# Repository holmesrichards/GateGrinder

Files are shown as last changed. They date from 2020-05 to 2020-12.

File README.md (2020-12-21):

# GateGrinder
Kosmo format synth module, 10 cm wide, to generate clocks and act on triggers and gates (called “signals” generally herein).

Signals come from three sources. There is a jack for an external CV input (±12V). There is a pushbutton for manually created gates. Finally, there is an internal clock to produce a stream of square gates. The clock can be switched On or Off and to Slow or Fast rate ranges, and its Rate can be set, on the front panel. (Slow is around 0.14 Hz to 15 Hz, fast is 3.2 Hz to 320 Hz using the specified components.)

If the Resize On/Off switch is set to Off, the OR of these three signal sources is sent to the Out jack. Otherwise the rising edges are used to trigger a one-shot whose output width is controlled by the Resize Narrow/Wide switch and the Width knob, and the resulting signals are sent to Out. Output widths can vary from about a few milliseconds to about 5 seconds.

(And yes, the width can be set to longer than the time between two pulses. It then ignores any pulses that come along until the resized pulse ends.)

The signal at the Out jack also goes to an inverter whose output goes to the ~Out jack. LEDs indicate when Out and ~Out are on. The rising and falling edges of the Out signal are used to generate trigger pulses which go to the On and Off jacks respectively.

So one can invert gates, change the lengths of gates, convert gates to triggers, convert triggers to gates, make a gate clock, make a trigger clock.

Repository at https://github.com/holmesrichards/GateGrinder includes KiCad format schematic, PCB design, and panel design. Latest versions in the repository contain  modifications I have not tested though others have reported they work; see tagged releases for versions I have verified.

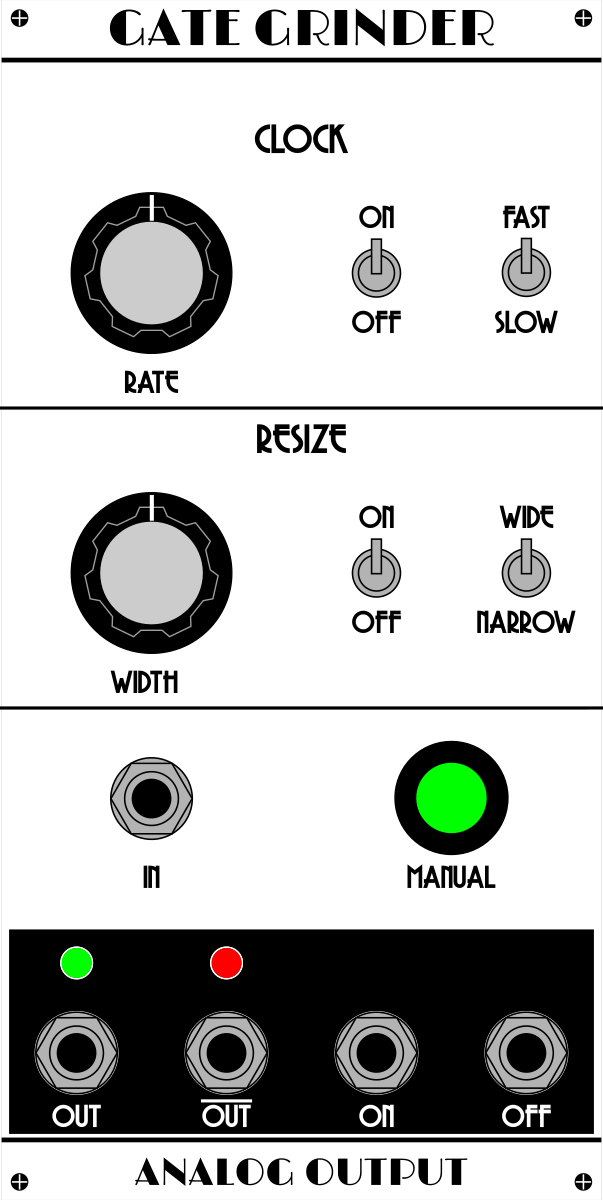
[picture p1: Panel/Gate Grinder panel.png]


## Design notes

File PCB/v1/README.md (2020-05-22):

# v1
This folder contains schematics, PCB, build notes, and BOM for the module as originally fabricated. PCB is too long and contains regular instead of wide transistor footprints. Outputs have fixed resistor voltage dividers instead of trimmer pots.

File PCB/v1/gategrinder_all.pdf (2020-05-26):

# GateGrinder

Kosmo format synth module, 10 cm wide, to generate clocks and act on triggers and gates (called “signals” generally herein).

Signals come from three sources. There is a jack for an external CV input (±12V). There is a pushbutton for manually created gates. Finally, there is an internal clock to produce a stream of square gates. The clock can be switched On or Off and to Slow or Fast rate ranges, and its Rate can be set, on the front panel. (Slow is around 0.14 Hz to 15 Hz, fast is 3.2 Hz to 320 Hz using the specified components.)

If the Resize On/Off switch is set to Off, the OR of these three signal sources is sent to the Out jack. Otherwise the rising edges are used to trigger a one-shot whose output width is controlled by the Resize Narrow/Wide switch and the Width knob, and the resulting signals are sent to Out. Output widths can vary from about a few milliseconds to about 5 seconds.

(And yes, the width can be set to longer than the time between two pulses. It then ignores any pulses that come along until the resized pulse ends.)

The signal at the Out jack also goes to an inverter whose output goes to the ~Out jack. LEDs indicate when Out and ~Out are on. The rising and falling edges of the Out signal are used to generate trigger pulses which go to the On and Off jacks respectively.

So one can invert gates, change the lengths of gates, convert gates to triggers, convert triggers to gates, make a gate clock, make a trigger clock.

Repository at https://github.com/holmesrichards/GateGrinder includes KiCad format schematic, PCB design, and panel design.

# Gate Grinder build notes

These build notes are for the first version of Gate Grinder. For the current version see https://github.com/holmesrichards/GateGrinder/blob/master/BUILD_NOTES.md (https://github.com/holmesrichards/GateGrinder/blob/master/BUILD_NOTES.md) . Differences pertain only to the main PCB.

This is a pretty standard Kosmo module. There are two PCBs, a large main one and a smaller panel PCB.

For some incomprehensible reason I made the main board about 15 mm too long to fit in a Kosmo case and then didn’t use the bottom 15 mm. Use a cutting wheel on a Dremel to cut 15 mm off the bottom of the main board (where the logo is).

Most components go on the rear of the main board. Jacks, LEDs, and push button go on the front of the main board along with a 1x14 pin header. Toggle switches and pots go on the front of the panel board and a 1x14 pin socket goes on the rear. Panel and main board are joined via the pin header/ socket and two 12 mm M3 spacers.

Toggle switches and pots need all nuts and washers removed before placing the panel. LEDs need either to have long enough legs to reach the main board or to have their legs extended with pieces of wire. The recommended push button fits the panel hole and, assuming a 1.6 mm panel, the solder lugs just barely extend to and through the main board. Note that since it is installed from the front of the panel, once it has been soldered the panel cannot be removed without cutting the push button loose.

With components as specified, the output levels are low, just under 4V. Replacing the 1.8k resistors in the output voltage dividers (R19, R21, R23, R25) with 1.2k will bring these up to 5V, or adjust however you like to suit your preferences.

BOM for the main board is here: https://github.com/holmesrichards/GateGrinder/blob/master/PCB/v1/gategrinder_v1_bom.md

BOM for the panel board is here: https://github.com/holmesrichards/GateGrinder/blob/master/PanelPCB/gategrinder_panelPCB_bom.md

# gategrinder BOM

Thu 14 May 2020 10:39:47 AM EDT

Generated from schematic by Eeschema 5.1.5-52549c5~84~ubuntu18.04.1

This is BOM for the main PCB only

These build notes are for the first version of Gate Grinder. For the current version see https://github.com/holmesrichards/GateGrinder/blob/master/gategrinder_bom.md (https://github.com/holmesrichards/GateGrinder/blob/master/gategrinder_bom.md) . Differences pertain only to the main PCB.

Component Count: 68
Value | Qty | Part | Description | Vendor
C1, C12 | 2 | 0.01uF | Unpolarized capacitor
C2, C14 | 2 | 2.2uF | Polarized capacitor
C3, C7, C8, C10, C11, C13 | 6 | 0.1uF | Unpolarized capacitor
C4, C17 | 2 | 47uF | Polarized capacitor
C5, C6 | 2 | 10uF | Polarized capacitor
C9, C15, C16 | 3 | 100pf | Unpolarized capacitor
D1, D2 | 2 | 1N5817 | 20V 1A Schottky Barrier Rectifier Diode, DO-41
D3, D4, D5, D6 | 4 | 1N4148 | 100V 0.15A standard switching diode, DO-35
D7, D8 | 2 | LED | Light emitting diode
J1 | 1 | EURO_PWR_2x5 Eurorack style power header
J3 | 1 | Conn_01x14 | Pin header, male 14 pins
J6, J7, J8, J9, J10 | 5 | AudioJack | ¼" Audio Jack
Q1, Q2, Q3, Q4, Q5 | 5 | BC547 | 0.1A Ic, 45V Vce, Small Signal NPN Transistor, TO-92
R1, R12, R20, R22, R24, R26 | 6 | 1k | Resistor
R2, R5, R6, R7, R9, R10, R13, R14, R17, R18 10 100k | Resistor
R3 | 1 | 1M | Resistor
R4, R11 | 2 | 10k | Resistor
R8 | 1 | 15k | Resistor
R15, R16 | 2 | RL | Resistor
R19, R21, R23, R25 | 4 | 1k8 | Resistor
SW3 | 1 | SW_Push | Push button switch, solder lugs, Tayda A-4326
U1 | 1 | NA556 | Dual Precision Timers, DIP-14/SOIC-14/SSOP-14
U2 | 1 | 4069 | Hex inverter
U3 | 1 | TL072 | Dual Low-Noise JFET-Input Operational Amplifiers, DIP-8/SOIC-8
U4 | 1 | 4071 | Quad Or 2 inputs
Also needed/recommended:

1 IC socket, 8 pin
3 IC sockets, 14 pin
1 Eurorack style power cable
2 knobs (I used MF-A03, Tayda A-1006) 4 M3x6mm screws
2 spacers, 12 mm, Tayda A-3317
4 Mounting screws

# gategrinder_panelPCB BOM

Mon 18 May 2020 11:31:23 PM EDT

Generated from schematic by Eeschema 5.1.5-52549c5~84~ubuntu18.04.1

This is BOM for the panel PCB only

Component Count: 7
Value Qty | Part | Description | Vendor
J1 | 1 | Conn_01x14 Pin socket, female 14 pins
RV1, RV2 2 | 100K | Potentiometer, 9 mm board mount, Tayda A-1848
SW1, SW3 2 | SW_SPST | Single Pole Single Throw (SPST) switch
SW2, SW4 2 | SW_SPDT | Switch, single pole double throw

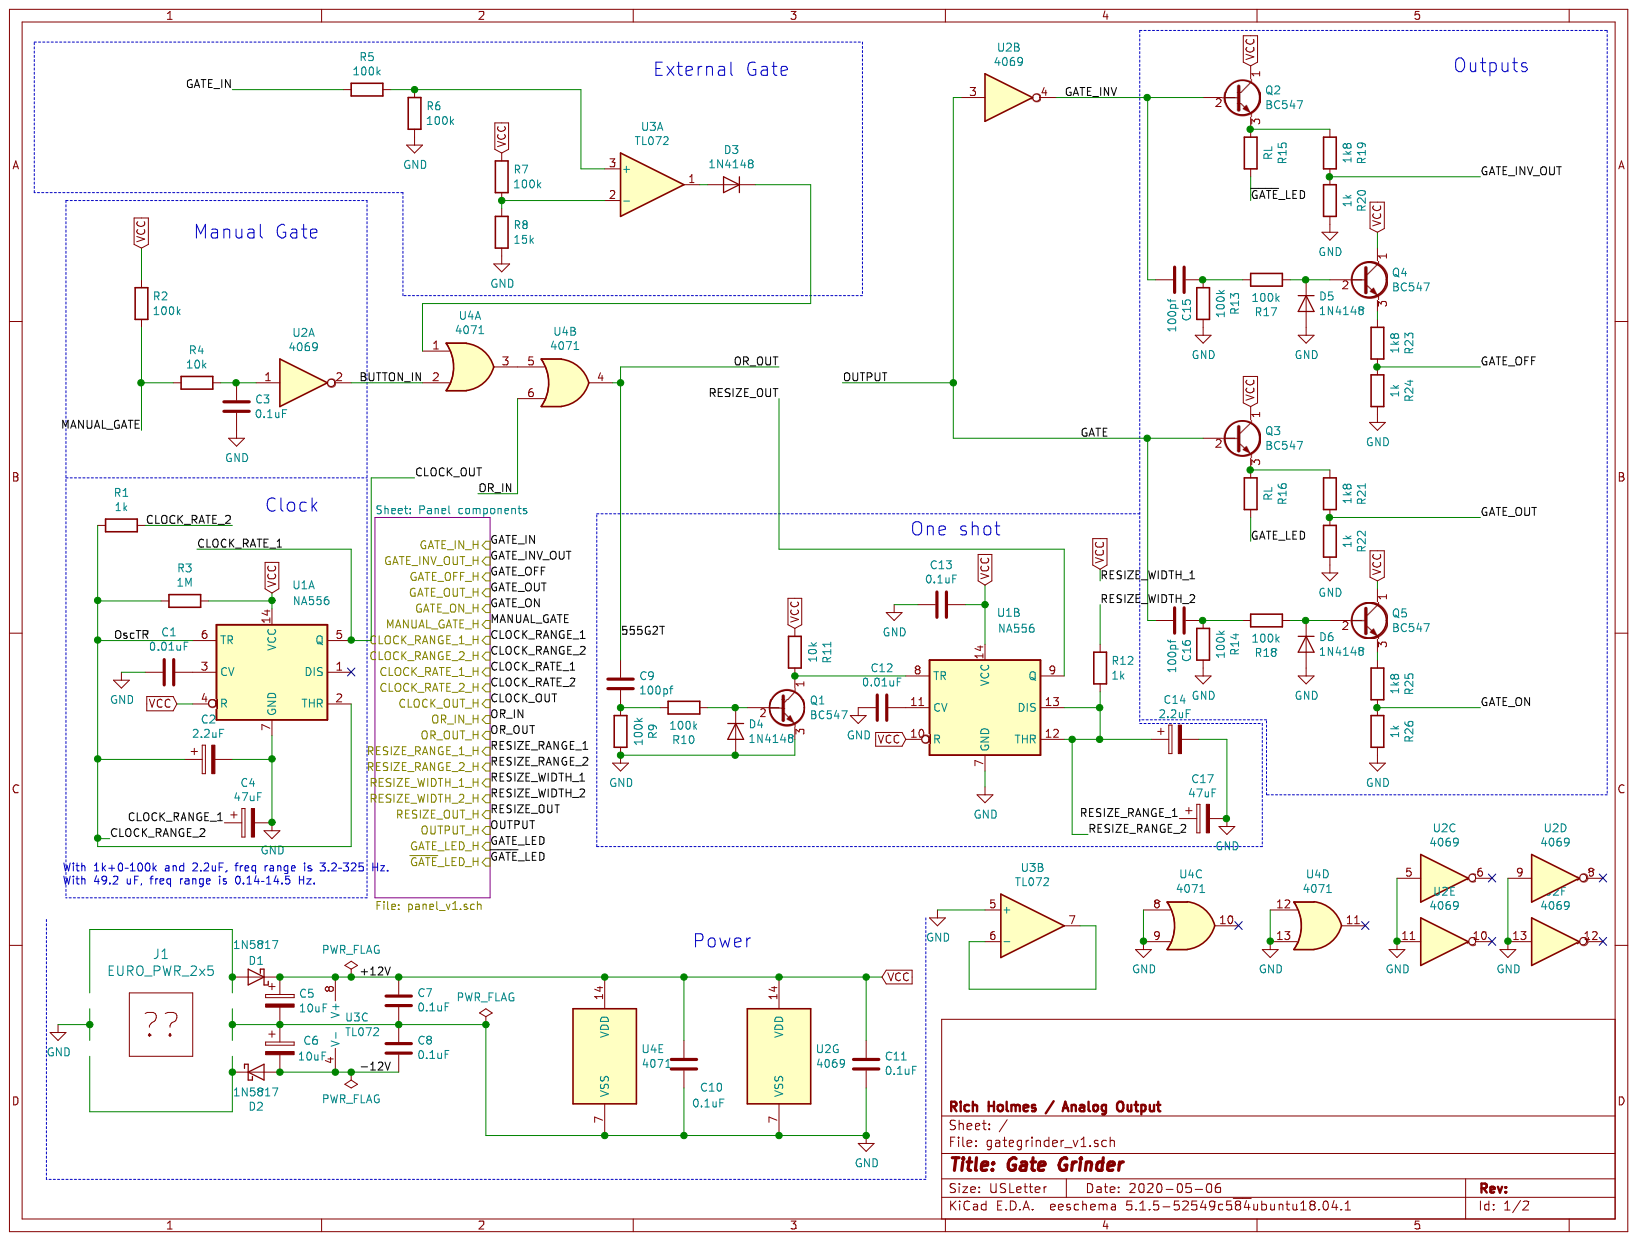
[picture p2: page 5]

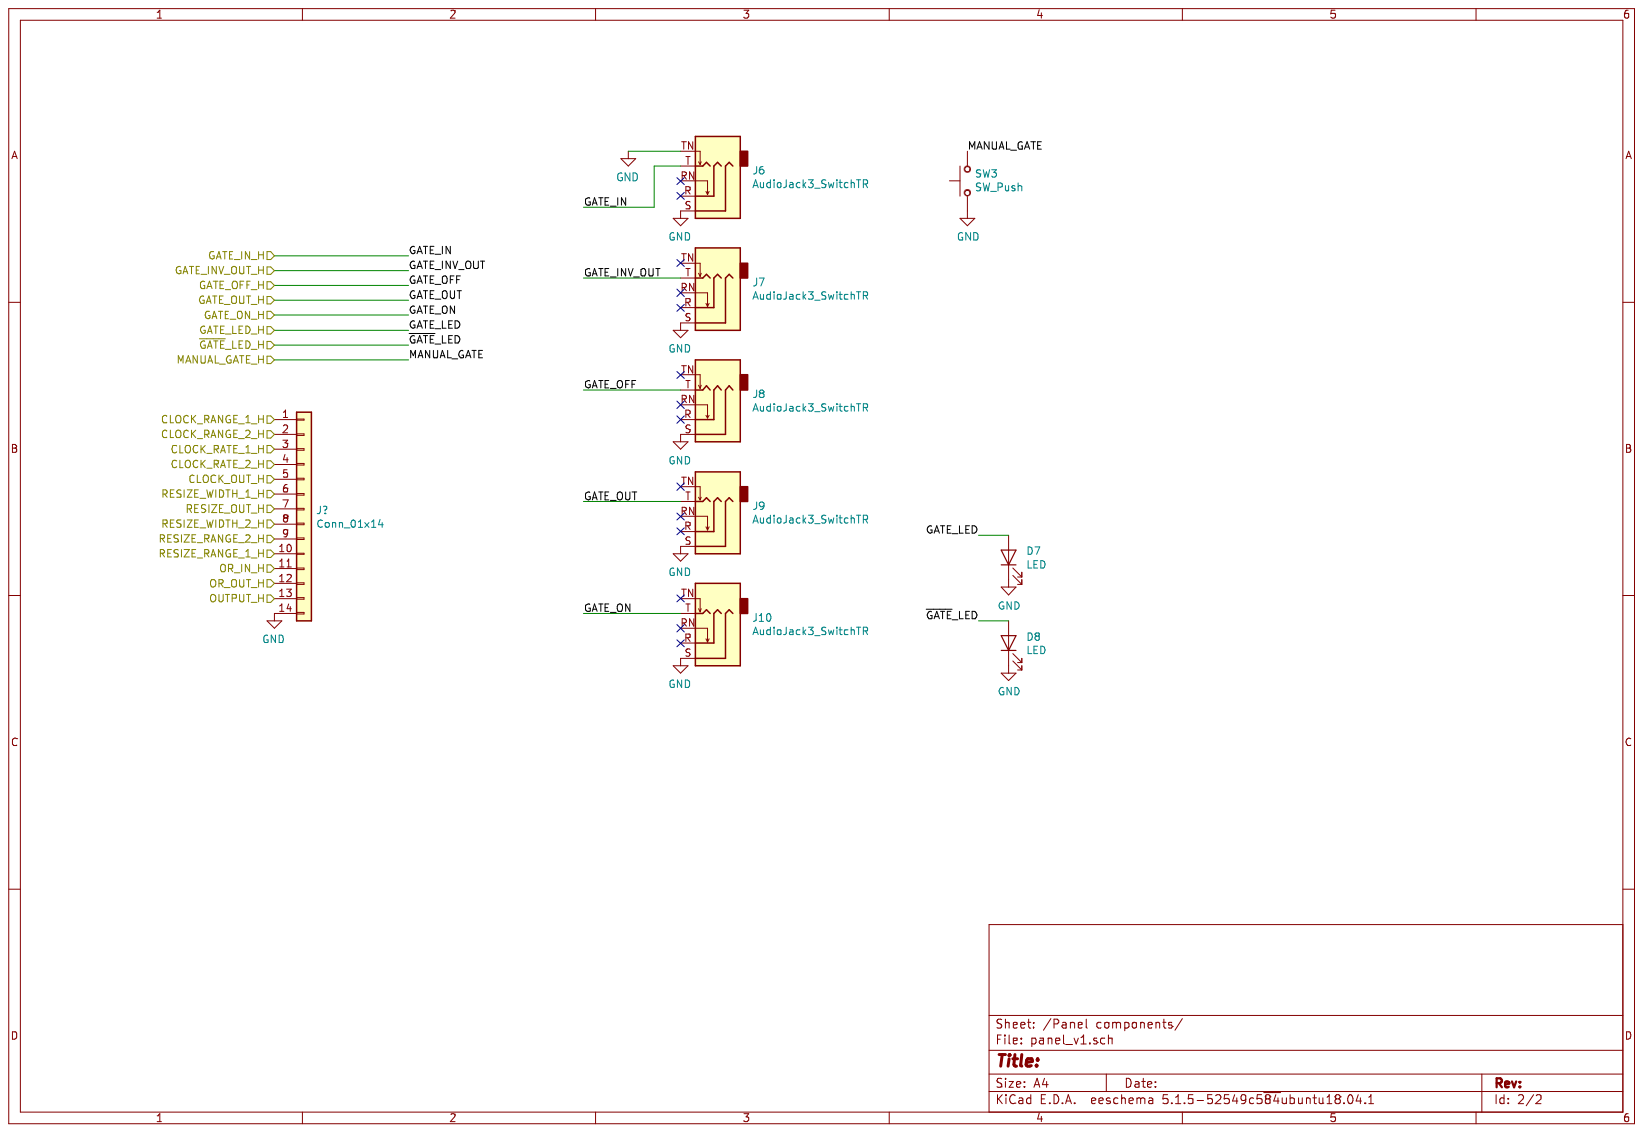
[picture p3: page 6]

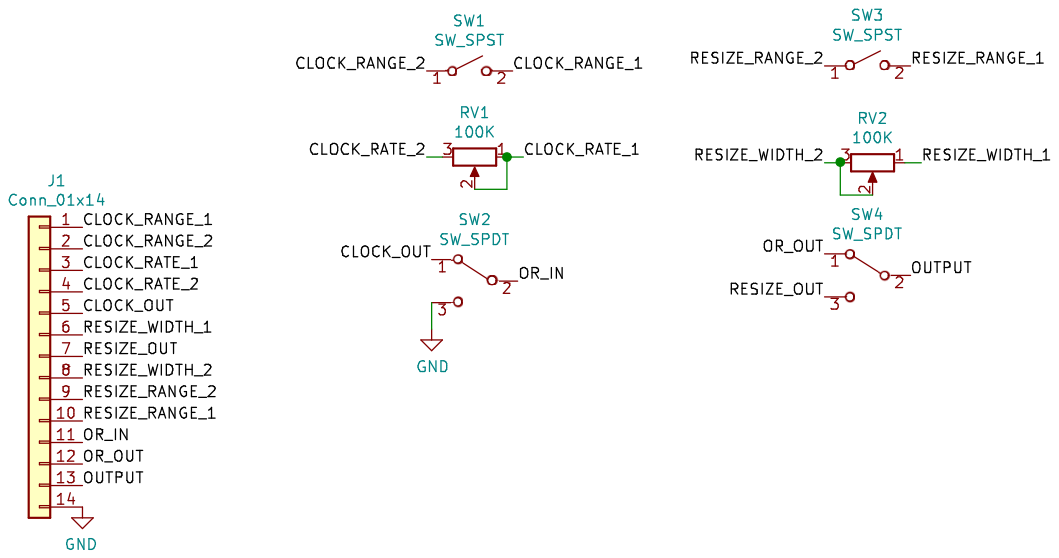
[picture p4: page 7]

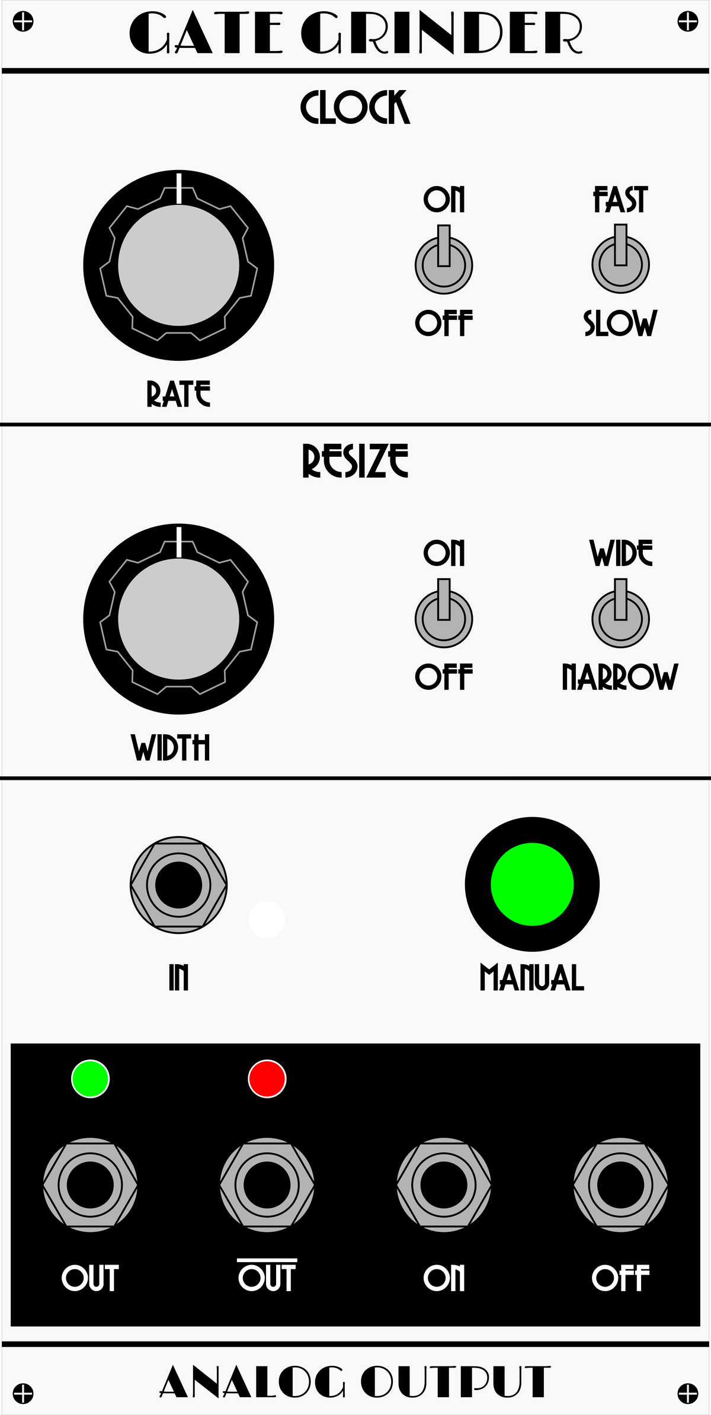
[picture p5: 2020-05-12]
Gate Grinder panel.png

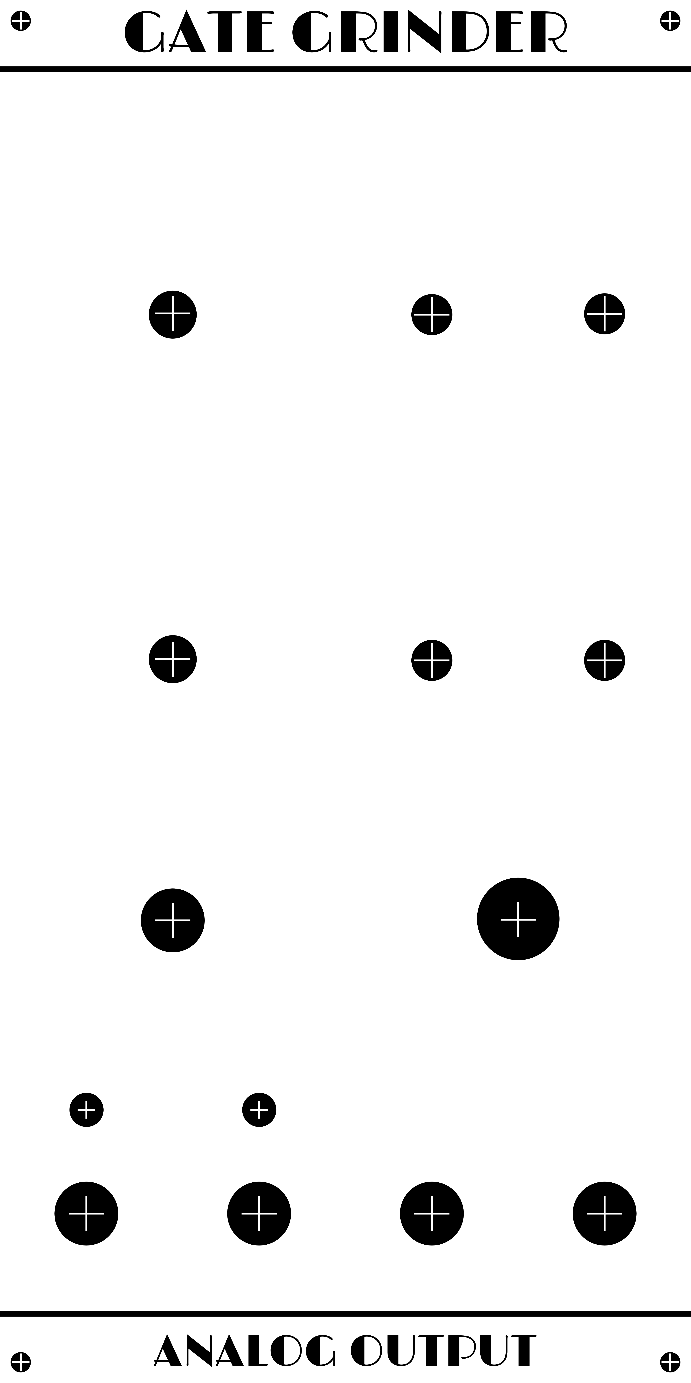
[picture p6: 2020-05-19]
Panel/Gate Grinder panel holes.png

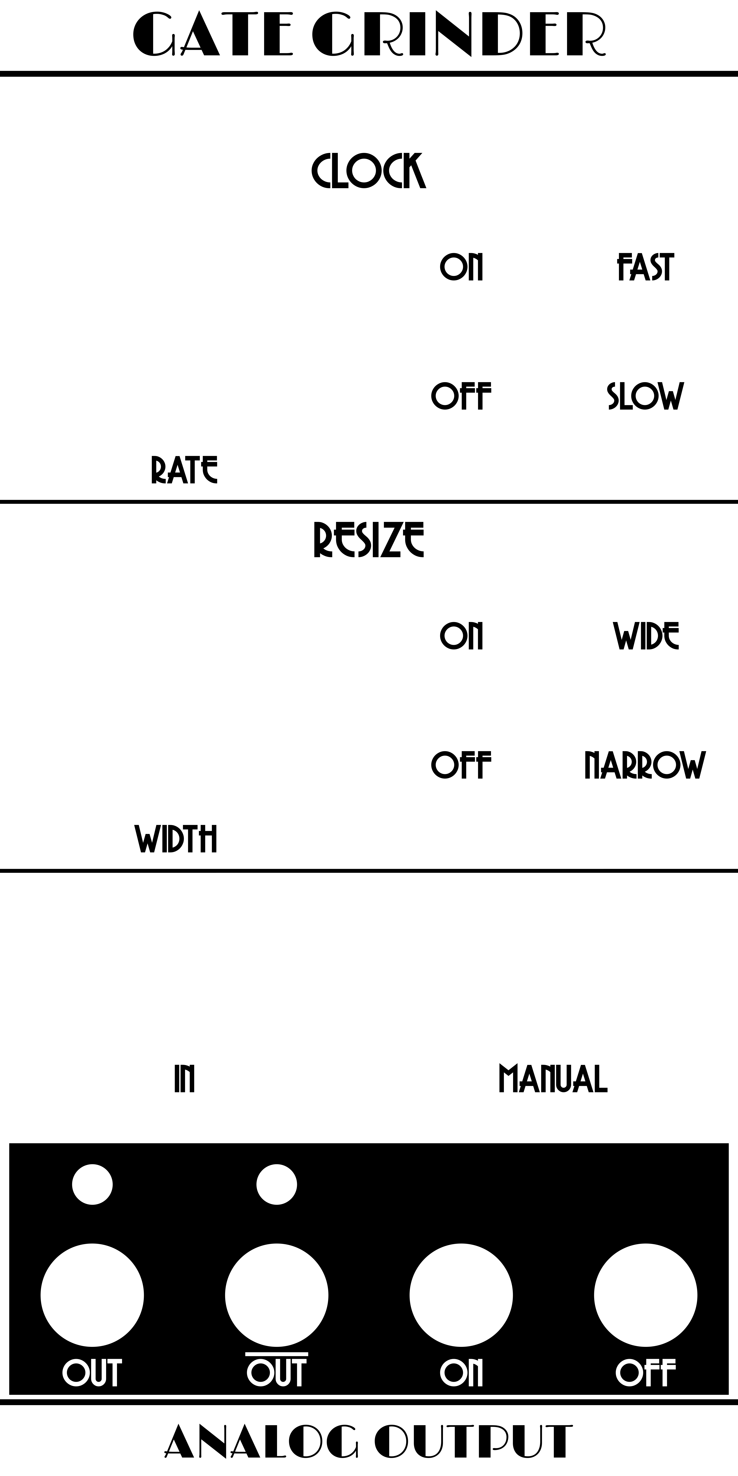
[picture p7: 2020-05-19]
Panel/Gate Grinder panel art.png

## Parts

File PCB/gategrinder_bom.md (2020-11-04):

# gategrinder BOM

Fri 22 May 2020 10:38:55 AM EDT

Generated from schematic by Eeschema 5.1.5-52549c5~84~ubuntu18.04.1

**This is BOM for the main PCB only**

**Component Count:** 64

| Value | Qty | Part | Description | Vendor |
| ----- | --- | ---- | --- | --- |
| C1, C12 | 2 | 0.01uF | Unpolarized capacitor |  |
| C2, C14 | 2 | 2.2uF | Polarized capacitor |  |
| C3, C7, C8, C10, C11, C13 | 6 | 0.1uF | Unpolarized capacitor |  |
| C4, C17 | 2 | 47uF | Polarized capacitor |  |
| C5, C6 | 2 | 10uF | Polarized capacitor |  |
| C9, C15, C16 | 3 | 100pf | Unpolarized capacitor |  |
| D1, D2 | 2 | 1N5817 | 20V 1A Schottky Barrier Rectifier Diode, DO-41 |  |
| D3, D4, D5, D6 | 4 | 1N4148 | 100V 0.15A standard switching diode, DO-35 |  |
| D7, D8 | 2 | LED | Light emitting diode |  |
| J1 | 1 | EURO_PWR_2x5 |  |  |
| J3 | 1 | Conn_01x14 | Generic connector, single row, 01x14, script generated (kicad-library-utils/schlib/autogen/connector/) |  |
| J6, J7, J8, J9, J10 | 5 | AudioJack3_SwitchTR | Audio Jack, 3 Poles (Stereo / TRS), Switched TR Poles (Normalling) |  |
| Q1, Q2, Q3, Q4, Q5 | 5 | BC547 | 0.1A Ic, 45V Vce, Small Signal NPN Transistor, TO-92 |  |
| R1, R12 | 2 | 1k | Resistor |  |
| R2, R5, R6, R7, R9, R10, R13, R14, R17, R18, R19 | 11 | 100k | Resistor |  |
| R3 | 1 | 1M | Resistor |  |
| R4, R11 | 2 | 10k | Resistor |  |
| R8 | 1 | 15k | Resistor |  |
| R15, R16 | 2 | RL* | Resistor |  |
| RV1, RV2, RV3, RV4 | 4 | 2k | Trim-potentiometer |  |
| SW3 | 1 | SW_Push | Push button switch, generic, two pins |  |
| U1 | 1 | NE556N | Dual Precision Timers, DIP-14/SOIC-14/SSOP-14 |  |
| U2 | 1 | 4069 | Hex inverter |  |
| U3 | 1 | TL072 | Dual Low-Noise JFET-Input Operational Amplifiers, DIP-8/SOIC-8 |  |
| U4 | 1 | 4071 | Quad Or 2 inputs |  |  

  *For R15–R16 use values that give you your desired LED brightness. Try them on a breadboard with your LED and 12V.

  Also needed/recommended:

- 1 IC socket, 8 pin
- 3 IC sockets, 14 pin
- 1 Eurorack style power cable
- 2 knobs (I used MF-A03, Tayda A-1006)
- 4 M3x6mm screws
- 2 spacers, 12 mm, Tayda A-3317
- 4 Mounting screws

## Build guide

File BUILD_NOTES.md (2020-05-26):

# Gate Grinder build notes

This is a pretty standard Kosmo module. There are two PCBs, a large main one and a smaller panel PCB. Most components go on the rear of the main board. Jacks, LEDs, and push button go on the front of the main board along with a 1x14 pin header. Toggle switches and pots go on the front of the panel board and a 1x14 pin socket goes on the rear. Panel and main board are joined via the pin header/socket and two 12 mm M3 spacers.

Toggle switches and pots need all nuts and washers removed before placing the panel. LEDs need either to have long enough legs to reach the main board or to have their legs extended with pieces of wire. The recommended push button fits the panel hole and, assuming a 1.6 mm panel, the solder lugs just barely extend to and through the main board. Install the switch from the front of the panel and solder the lugs in place. If you later need to remove the panel, you can unscrew the switch from its base.

For current version, use the trimmers to adjust output voltage levels. (First version had fixed resistors on the outputs.)

BOM for the main board is here: https://github.com/holmesrichards/GateGrinder/blob/master/PCB/gategrinder_bom.md

BOM for the panel board is here: https://github.com/holmesrichards/GateGrinder/blob/master/PanelPCB/gategrinder_panelPCB_bom.md

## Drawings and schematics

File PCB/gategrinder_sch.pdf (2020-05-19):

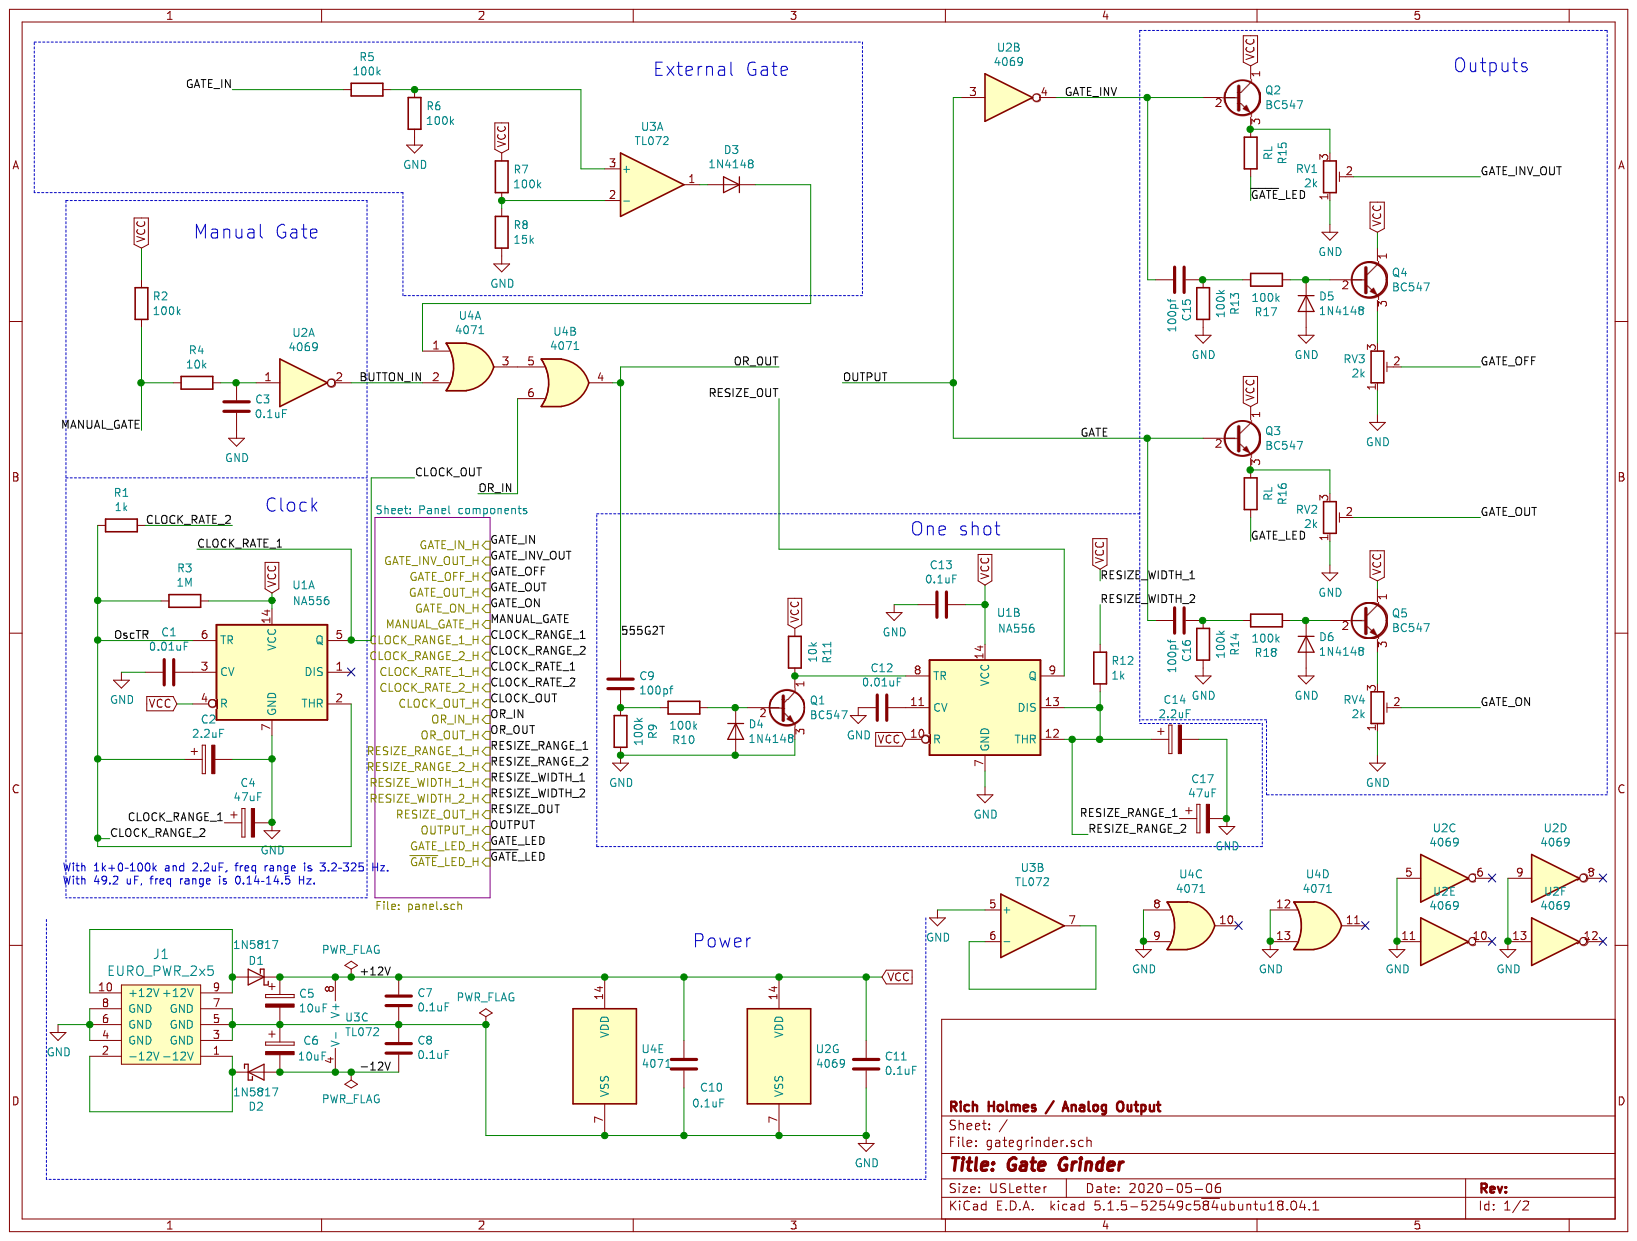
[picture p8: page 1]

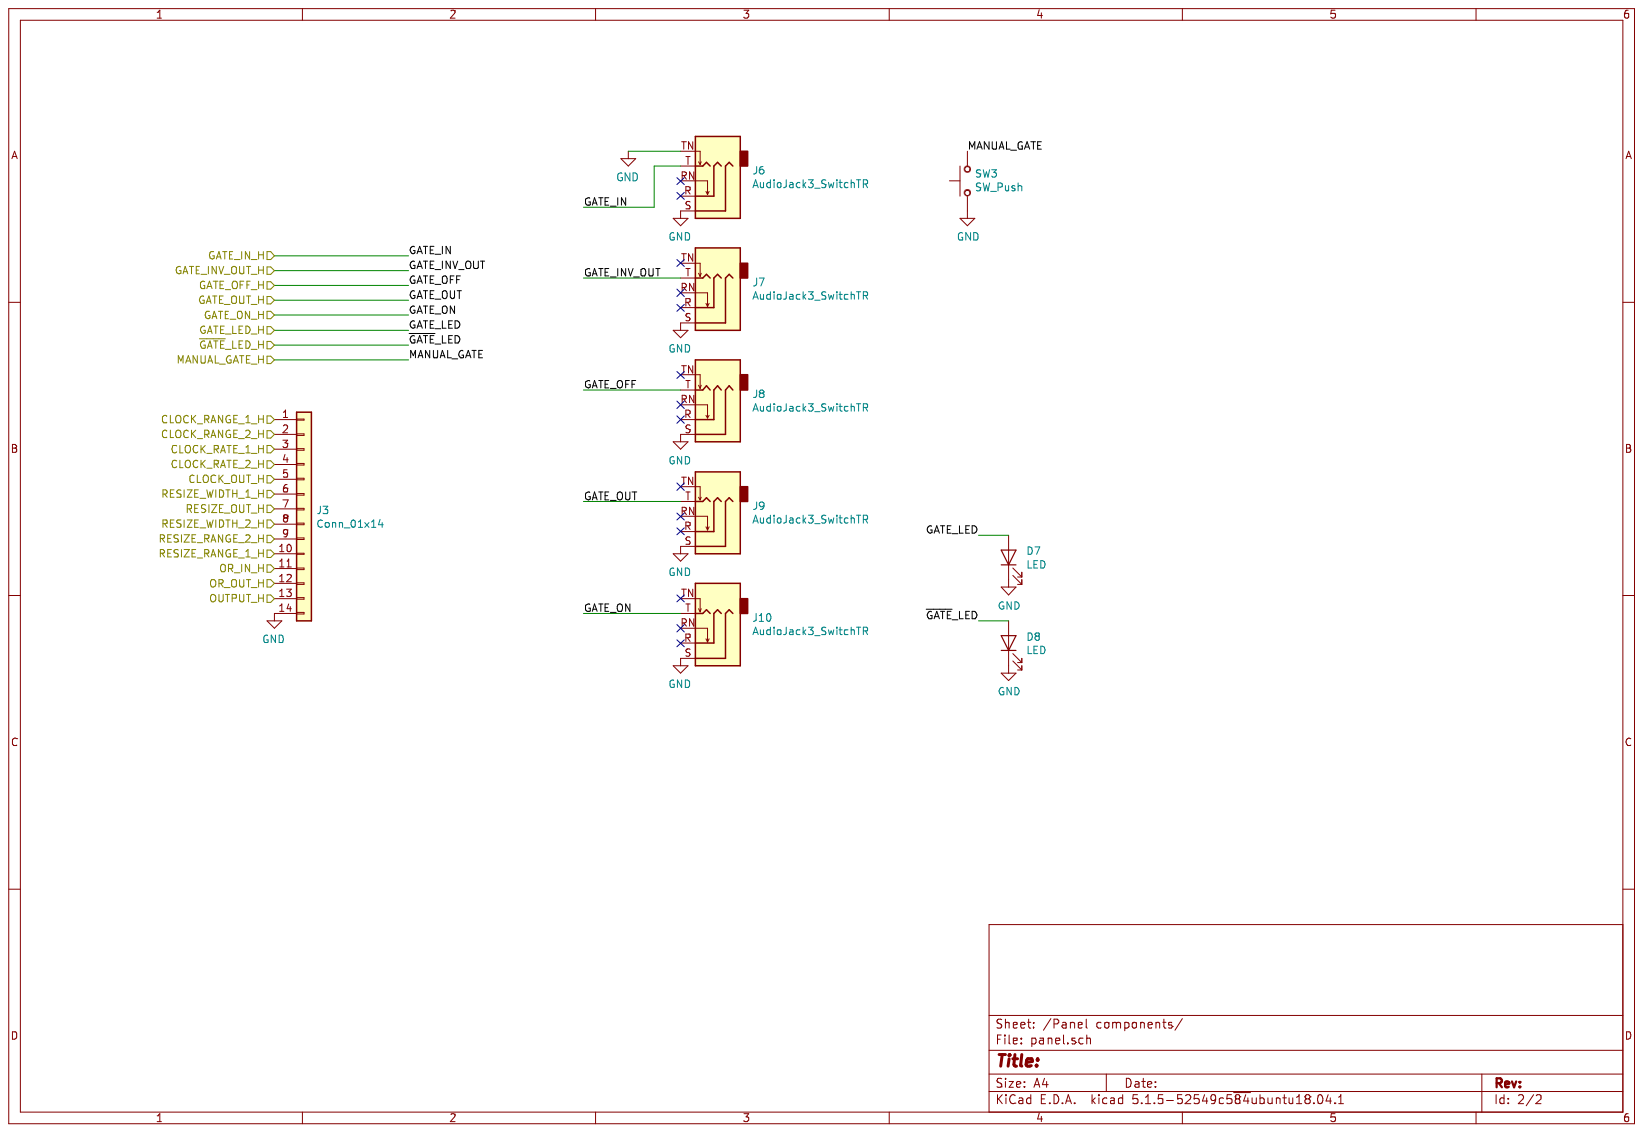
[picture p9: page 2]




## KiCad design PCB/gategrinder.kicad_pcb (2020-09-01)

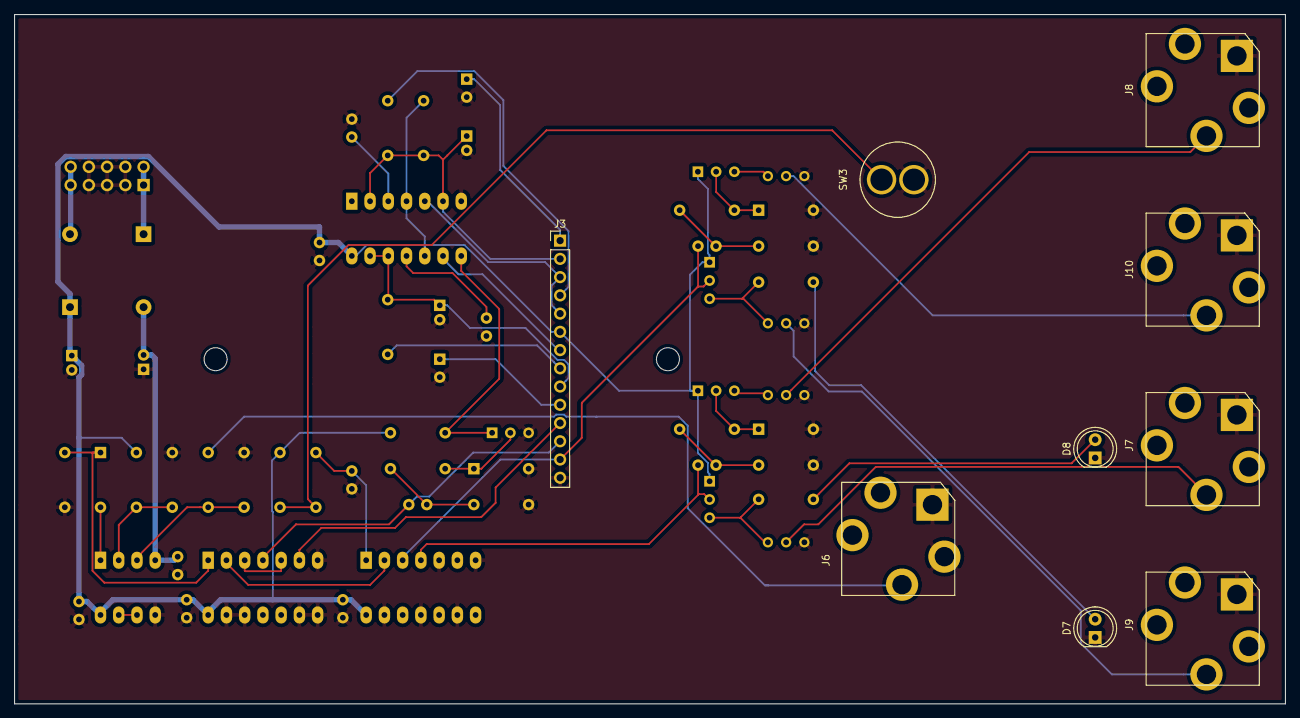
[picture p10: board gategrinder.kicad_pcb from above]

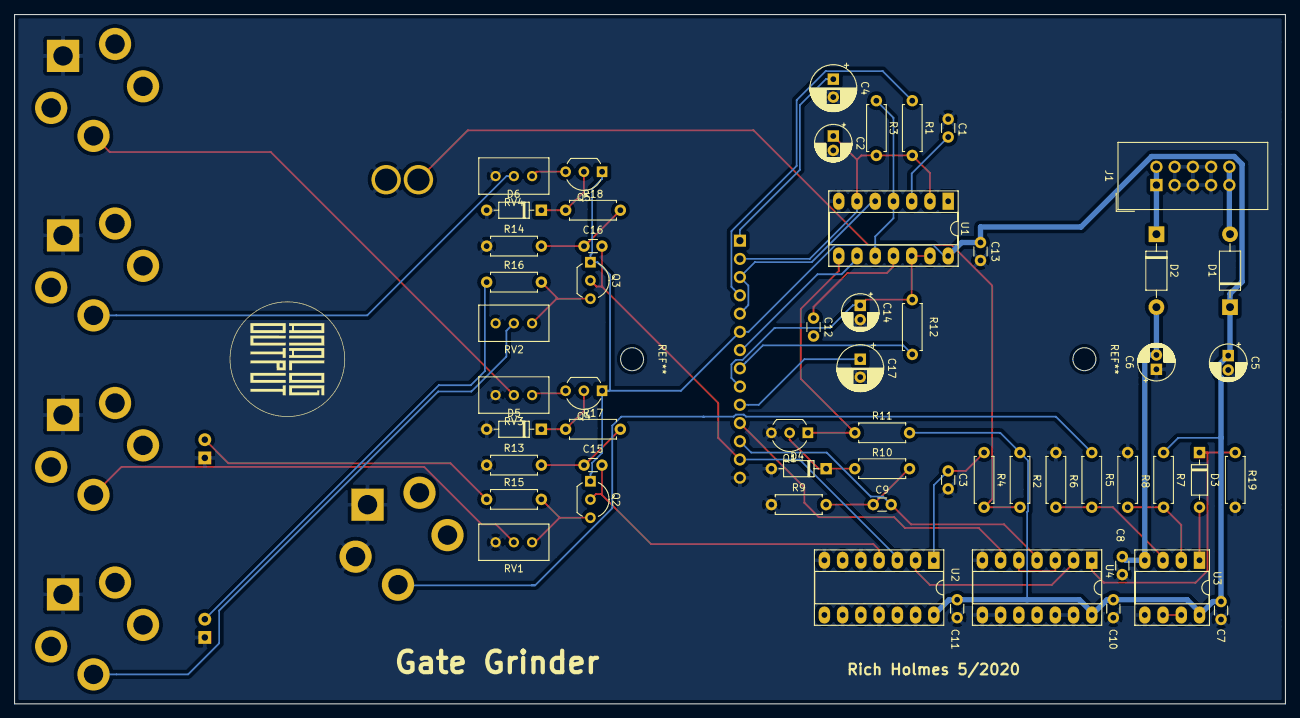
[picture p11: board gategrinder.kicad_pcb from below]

Board: 2 copper layers, 177.0 x 96.0 mm, 65 parts (56 on the bottom side), 46 nets.

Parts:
C1, C12: 0.01uF; C_Disc_D3.0mm_W1.6mm_P2.50mm
C2, C14: 2.2uF; CP_Radial_D5.0mm_P2.00mm
C3, C7, C8, C10, C11, C13: 0.1uF; C_Disc_D3.0mm_W1.6mm_P2.50mm
C4, C17: 47uF; CP_Radial_D6.3mm_P2.50mm
C5, C6: 10uF; CP_Radial_D5.0mm_P2.00mm
C9, C15, C16: 100pf; C_Disc_D3.0mm_W1.6mm_P2.50mm
D1, D2: 1N5817; D_DO-41_SOD81_P10.16mm_Horizontal
D3, D4, D5, D6: 1N4148; D_DO-35_SOD27_P7.62mm_Horizontal
D7, D8: LED; LED_D5.0mm
J1: EURO_PWR_2x5; IDC-Header_2x05_P2.54mm_Vertical
J3: Conn_01x14; PinHeader_1x14_P2.54mm_Vertical
J6, J7, J8, J9, J10: AudioJack3_SwitchTR; Jack_6.35mm_PJ_629HAN
Q1, Q2, Q3, Q4, Q5: BC547; TO-92_Inline_Wide
R1, R12: 1k; R_Axial_DIN0207_L6.3mm_D2.5mm_P7.62mm_Horizontal
R2, R5, R6, R7, R9, R10, R13, R14, R17, R18, R19: 100k; R_Axial_DIN0207_L6.3mm_D2.5mm_P7.62mm_Horizontal
R3: 1M; R_Axial_DIN0207_L6.3mm_D2.5mm_P7.62mm_Horizontal
R4, R11: 10k; R_Axial_DIN0207_L6.3mm_D2.5mm_P7.62mm_Horizontal
R8: 15k; R_Axial_DIN0207_L6.3mm_D2.5mm_P7.62mm_Horizontal
R15, R16: RL; R_Axial_DIN0207_L6.3mm_D2.5mm_P7.62mm_Horizontal
RV1, RV2, RV3, RV4: 2k; Potentiometer_Bourns_3296W_Vertical
SW3: SW_Push; Tayda-PBS11-pushbutton
U1: NE556N; DIP-14_W7.62mm_Socket_LongPads
U2: 4069; DIP-14_W7.62mm_Socket_LongPads
U3: TL072; DIP-8_W7.62mm_Socket_LongPads
U4: 4071; DIP-14_W7.62mm_Socket_LongPads

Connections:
/555G2T: C9.2, J3.12, U4.4
/-12V: C6.2, C8.1, D2.2, U3.4
/BUTTON_IN: U2.2, U4.2
/CLOCK_OUT: J3.3, J3.5, U1.5
/CLOCK_RANGE_1: C4.1, J3.1
/CLOCK_RANGE_2: C2.1, J3.2, R1.2, R3.2, U1.2, U1.6
/CLOCK_RATE_2: J3.4, R1.1
/GATE: C16.1, J3.13, Q3.2, U2.3
/GATE_IN: J6.T, R5.2
/GATE_INV: C15.1, Q2.2, U2.4
/GATE_INV_OUT: J7.T, RV1.2
/GATE_LED: D7.2, R16.1
/GATE_OFF: J8.T, RV3.2
/GATE_ON: J10.T, RV4.2
/GATE_OUT: J9.T, RV2.2
/MANUAL_GATE: R2.2, R4.2, SW3.2
/OR_IN: J3.11, U4.6
/RESIZE_OUT: J3.7, U1.9
/RESIZE_RANGE_1: C17.1, J3.10
/RESIZE_RANGE_2: C14.1, J3.9, R12.2, U1.12, U1.13
/RESIZE_WIDTH_2: J3.8, R12.1
/~GATE~_LED: D8.2, R15.1
GND: C1.2, C2.2, C3.2, C4.2, C5.2, C6.1, C7.1, C8.2, C10.1, C11.1, C12.2, C13.2, C14.2, C17.2, D4.2, D5.2, D6.2, D7.1, D8.1, J1.3, J1.4, J1.5, J1.6, J1.7, J1.8, J3.14, J6.S, J6.TN, J7.S, J8.S, J9.S, J10.S, Q1.3, R6.2, R8.2, R9.1, R13.1, R14.1, R19.2, RV1.1, RV2.1, RV3.1, RV4.1, SW3.1, U1.7, U2.5, U2.7, U2.9, U2.11, U2.13, U3.5, U4.7, U4.8, U4.9, U4.12, U4.13
unnamed: C1.1, U1.3
unnamed: C3.1, R4.1, U2.1
unnamed: C9.1, R9.2, R10.1
unnamed: C12.1, U1.11
unnamed: C15.2, R13.2, R17.1
unnamed: C16.2, R14.2, R18.1
unnamed: D1.2, J1.9, J1.10
unnamed: D2.1, J1.1, J1.2
unnamed: D3.1, R19.1, U4.1
unnamed: D3.2, U3.1
unnamed: D4.1, Q1.2, R10.2
unnamed: D5.1, Q4.2, R17.2
unnamed: D6.1, Q5.2, R18.2
unnamed: Q1.1, R11.1, U1.8
unnamed: Q2.3, R15.2, RV1.3
unnamed: Q3.3, R16.2, RV2.3
unnamed: Q4.3, RV3.3
unnamed: Q5.3, RV4.3
unnamed: R5.1, R6.1, U3.3
unnamed: R7.2, R8.1, U3.2
unnamed: U3.6, U3.7
unnamed: U4.3, U4.5
VCC: C5.1, C7.2, C10.2, C11.2, C13.1, D1.1, J3.6, Q2.1, Q3.1, Q4.1, Q5.1, R2.1, R3.1, R7.1, R11.2, U1.4, U1.10, U1.14, U2.14, U3.8, U4.14

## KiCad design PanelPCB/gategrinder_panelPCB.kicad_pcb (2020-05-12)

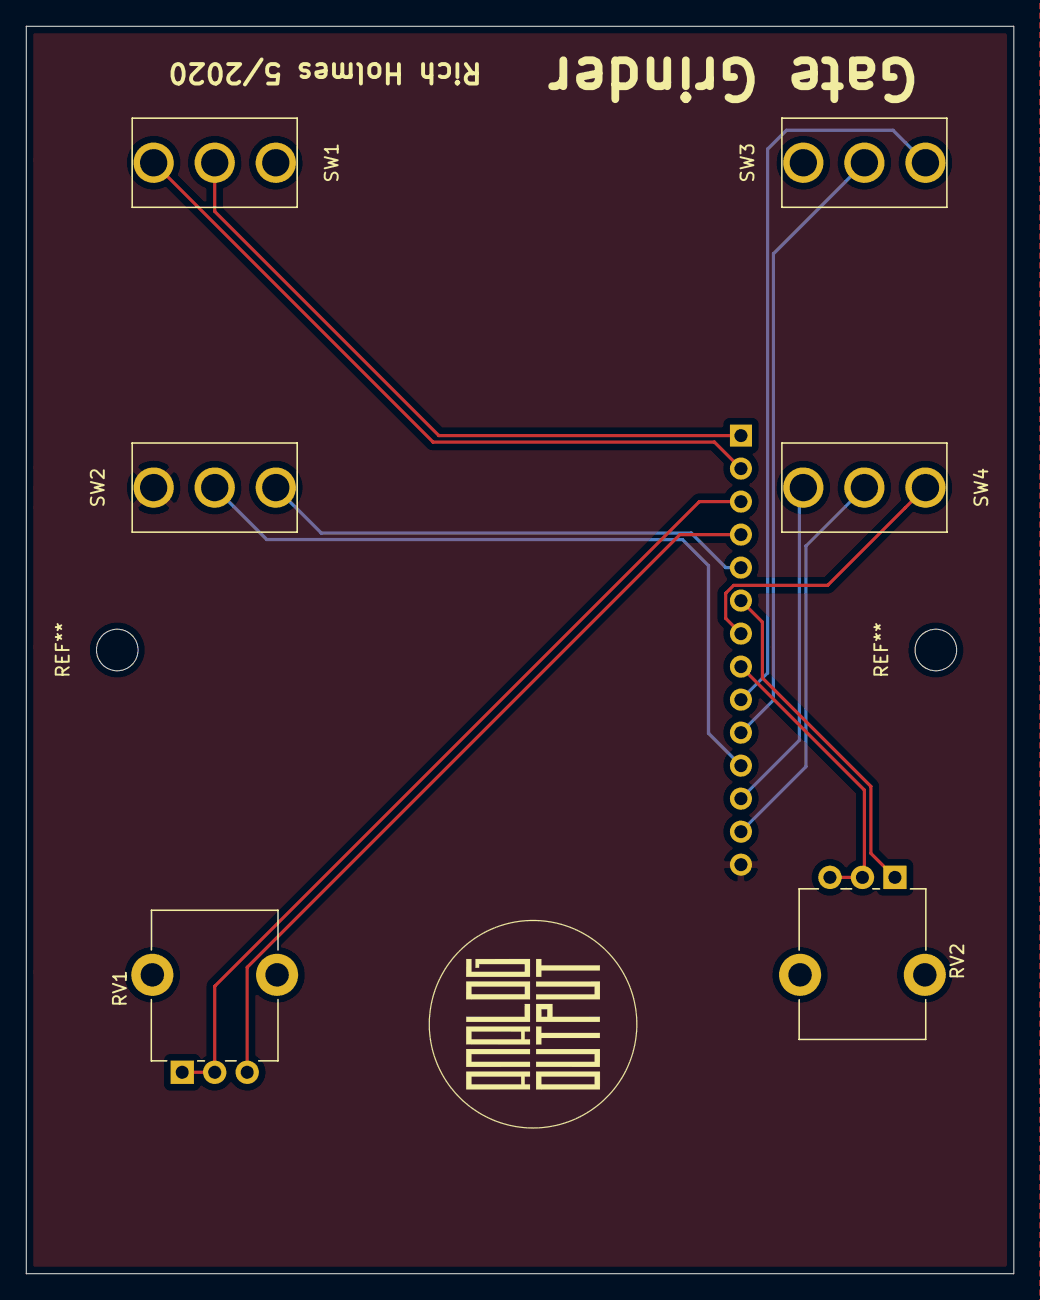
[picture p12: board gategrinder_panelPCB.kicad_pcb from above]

Board: 2 copper layers, 76.0 x 96.0 mm, 7 parts (1 on the bottom side), 14 nets.

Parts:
J1: Conn_01x14; PinSocket_1x14_P2.54mm_Vertical
RV1, RV2: 100K; Potentiometer_Alpha_RD901F-40-00D_Single_Vertical_CircularH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
SW1, SW3: SW_SPST; SPDT-toggle-switch-1M-series
SW2, SW4: SW_SPDT; SPDT-toggle-switch-1M-series

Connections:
/CLOCK_OUT: J1.5, SW2.1
/CLOCK_RANGE_1: J1.1, SW1.2
/CLOCK_RANGE_2: J1.2, SW1.1
/CLOCK_RATE_1: J1.3, RV1.1, RV1.2
/CLOCK_RATE_2: J1.4, RV1.3
/OR_IN: J1.11, SW2.2
/OR_OUT: J1.12, SW4.1
/OUTPUT: J1.13, SW4.2
/RESIZE_OUT: J1.7, SW4.3
/RESIZE_RANGE_1: J1.10, SW3.2
/RESIZE_RANGE_2: J1.9, SW3.1
/RESIZE_WIDTH_1: J1.6, RV2.1
/RESIZE_WIDTH_2: J1.8, RV2.2, RV2.3
GND: J1.14, SW2.3

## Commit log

2020-02-23 Initial version
    [gategrinder.kicad_pcb, gategrinder.sch]
2020-03-01 Fix power header
    [gategrinder.sch]
2020-05-10 Reorganize, add panel project
    [gategrinder.kicad_pcb, gategrinder.sch, gategrinder_panel.kicad_pcb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]
2020-05-10 Libraries cleanup and silkscreen work
    [gategrinder.kicad_pcb, gategrinder_panel.kicad_pcb]
2020-05-12 Rename panel to panelPCB; final tweaks; Gerbers
    [gategrinder-B_Cu.gbr, gategrinder-B_Mask.gbr, gategrinder-B_Paste.gbr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]
2020-05-17 Panel project
    [gategrinder_panel-B_Cu.gbr, gategrinder_panel-B_Mask.gbr, gategrinder_panel-B_Paste.gbr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]
2020-05-17 Real first version
    [gategrinder_panel.kicad_pcb, gategrinder_panel.sch]
2020-05-18 Shorten main board; widen transistor footprints
    [gategrinder.kicad_pcb, gategrinder.sch]
2020-05-19 Panel revision
    [gategrinder_panel-B_Cu.gbr, gategrinder_panel-B_Mask.gbr, gategrinder_panel-B_Paste.gbr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]
2020-05-19 BOMs and build notes
    [gategrinder.kicad_pcb]
2020-05-19 Schematics PDFs
2020-05-19 Replace fixed resistor output voltage dividers with trimmers
    [gategrinder-B_Cu.gbr, gategrinder-B_Mask.gbr, gategrinder-B_Paste.gbr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]
2020-05-22 More V1 files and update current boms
    [gategrinder_v1.sch, panel_v1.sch]
2020-05-22 Note on output resistors
2020-05-26 Letter size
    [panel.sch]
2020-05-26 Correct info on push button
2020-05-31 NA556 -> NE556
    Unless I’m mistaken, this chip is supposed to be the NE556.
2020-05-31 NA556 -> NE556N
    [gategrinder.kicad_pcb, gategrinder.sch, gategrinder_v1.kicad_pcb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]
2020-06-13 Added pulldown for OR
    [gategrinder.sch]
2020-09-01 Gerbers update
    [gategrinder-B_Cu.gbr, gategrinder-B_Mask.gbr, gategrinder-B_Paste.gbr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]
2020-11-04 Add R19 to BOM
